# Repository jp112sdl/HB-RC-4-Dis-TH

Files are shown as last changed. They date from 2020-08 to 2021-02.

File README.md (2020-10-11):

# HB-RC-4-Dis-TH
## 4fach Wandtaster mit Display und Temperatursensor

Als Vorlage/Idee diente das [AVM FRITZ!DECT 440](https://avm.de/produkte/fritzdect/fritzdect-440/).

### Aufbau:

An den 4 Ecken befinden sich Taster, um über 4 verschiedenen Tasterkanäle Geräte zu steuern.<br/>
Unten mittig ist der Mode-Taster:
- langes Drücken = Anlernen oder (ganz lange) RESET
- kurzes Drücken = Anzeige der Tasterbeschriftung

In Ruhe werden auf dem Display die Temperatur (und wahlweise Luftfeuchtigkeit) sowie der Batteriezustand angezeigt.
Wird der Mode-Taster kurz gedrückt, erscheint für die in den Geräteeinstellungen festgelegte "Display Timeout" Zeit die Taster-Beschriftung.

Als Beschriftung lassen sich
- eine Überschrift (optional)
- 1 bis 2 Zeilen Beschriftungstext

hinterlegen

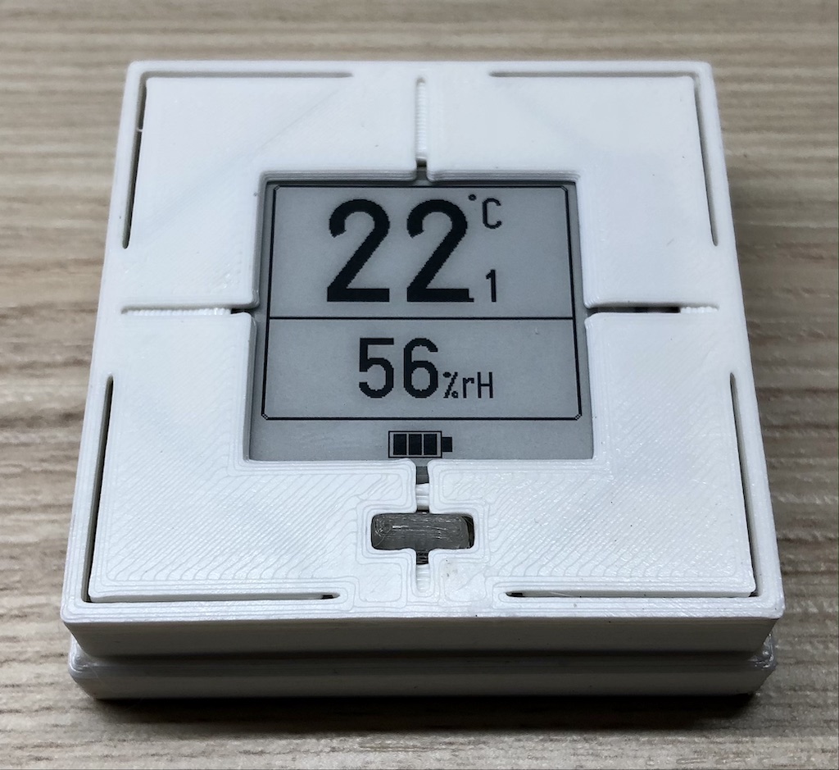
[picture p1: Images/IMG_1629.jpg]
device

<br><br>

### Prototyp

Nur Temperaturanzeige:<br>
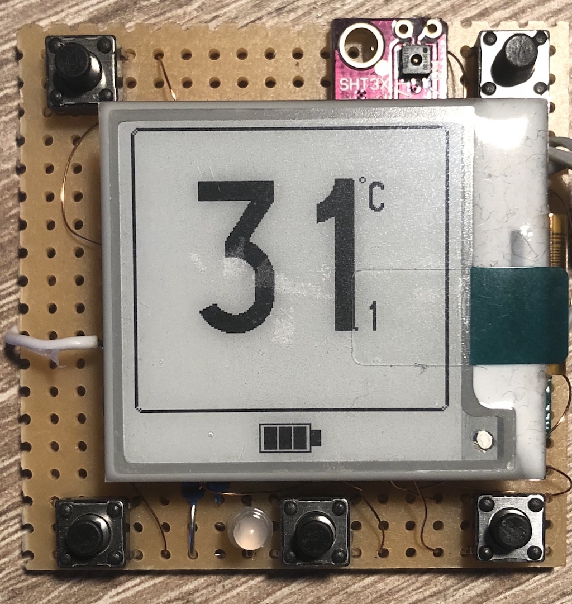
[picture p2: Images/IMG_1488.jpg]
<br><br>
Temperatur- und Luftfeuchtigkeit:<br>
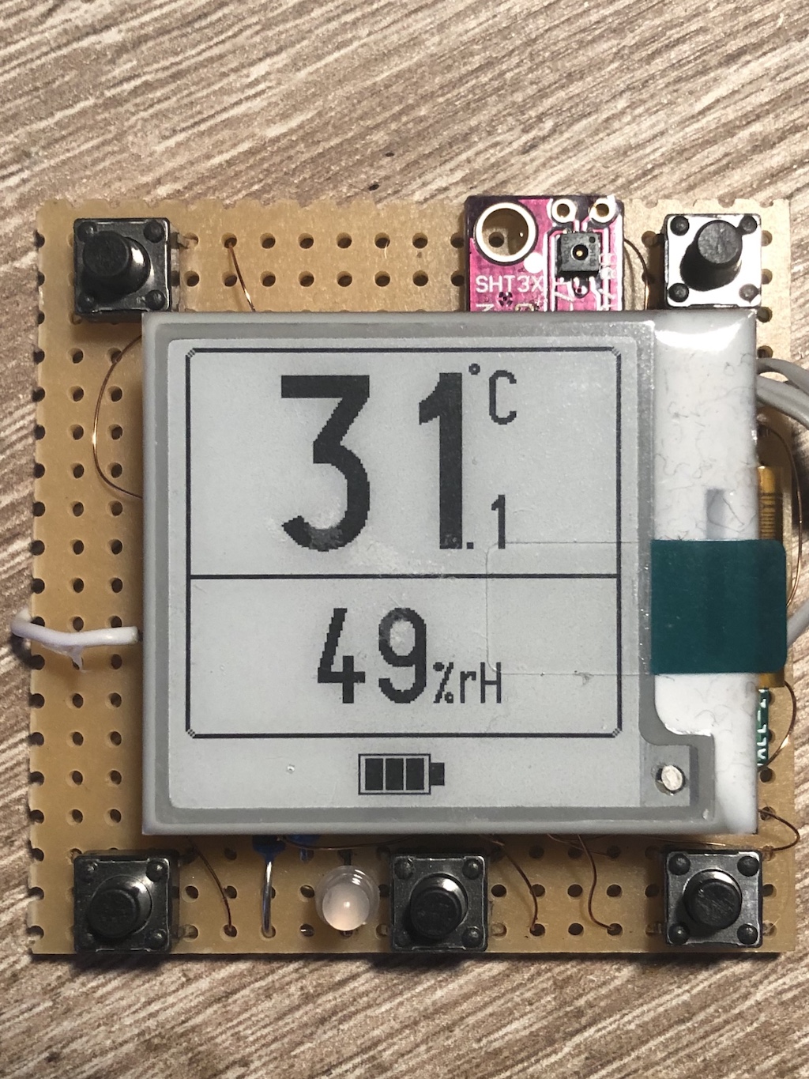
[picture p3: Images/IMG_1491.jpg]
<br><br>
Tasterbeschriftungen:<br>
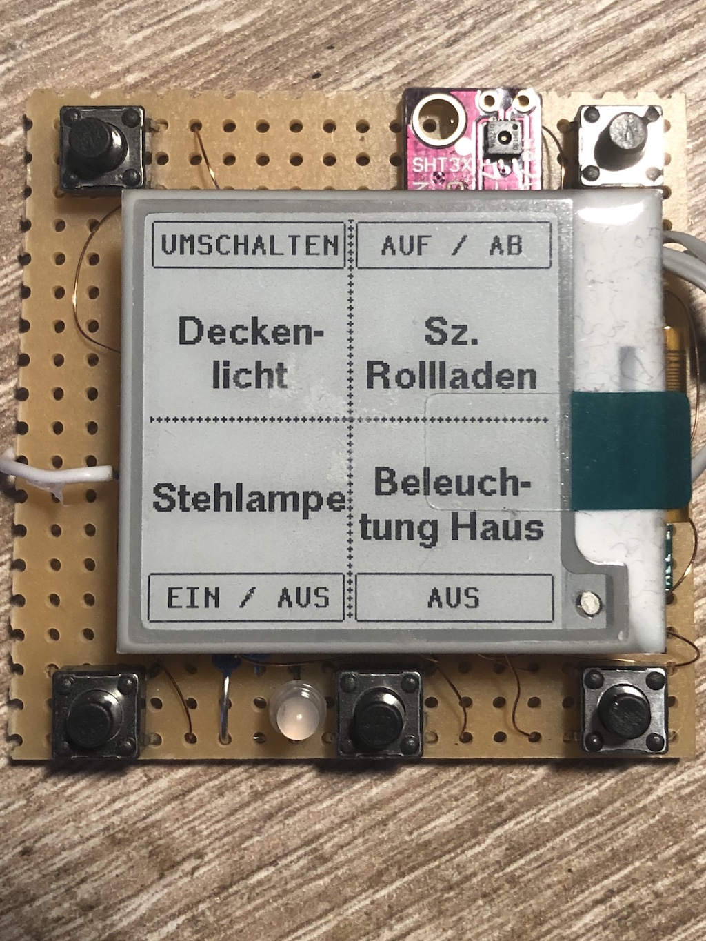
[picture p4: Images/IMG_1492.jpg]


### PCB Version 2.1

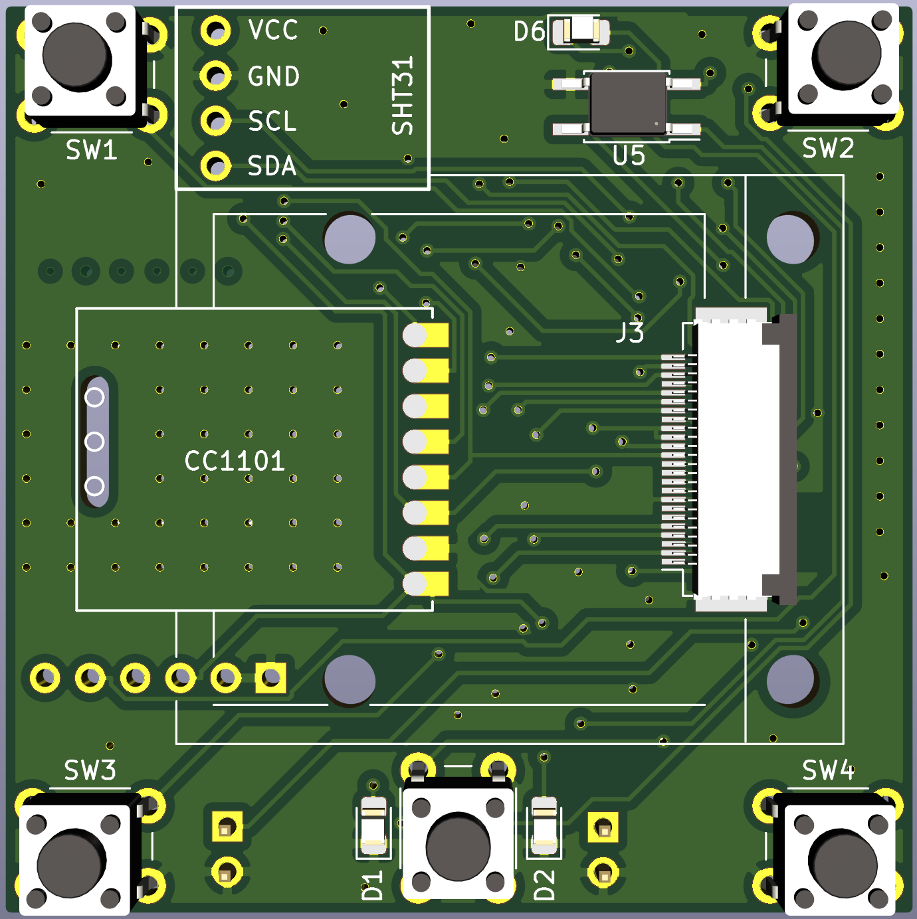
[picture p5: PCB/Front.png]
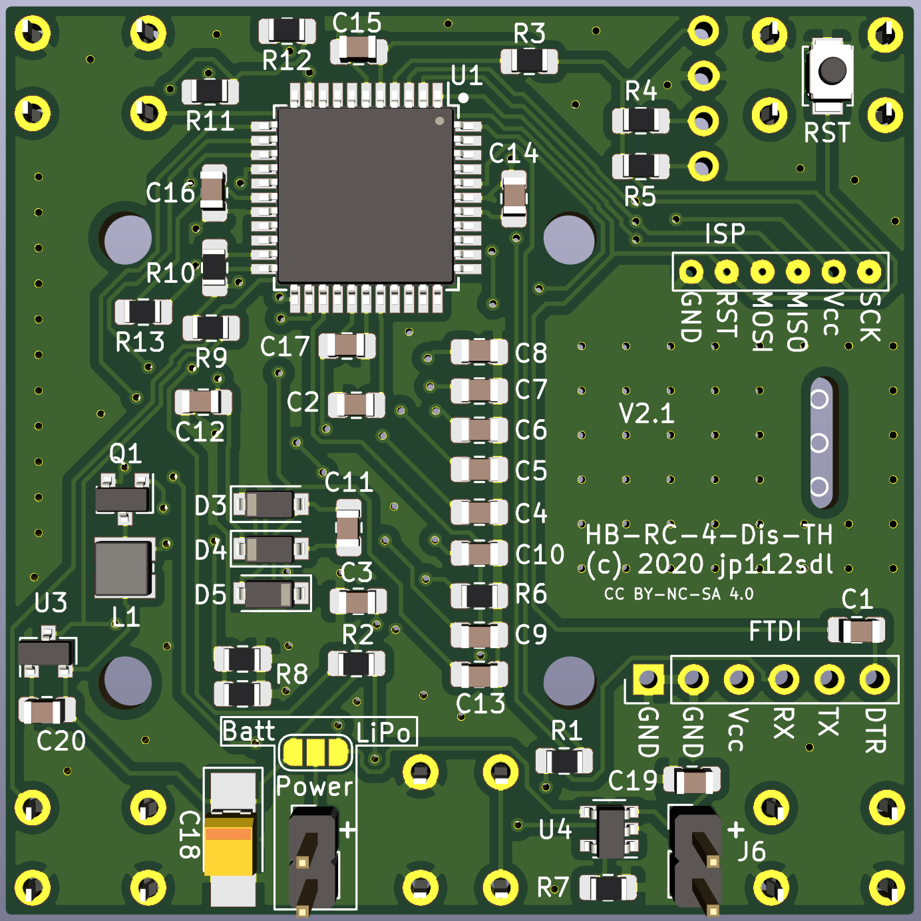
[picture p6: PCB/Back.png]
<br>
**[Abstandhalter](https://github.com/jp112sdl/HB-RC-4-Dis-TH/blob/master/PCB/HB-RC-4-Dis-TH%20ePaper%20Spacer.stl) zwischen Platine und ePaper:**<br/>
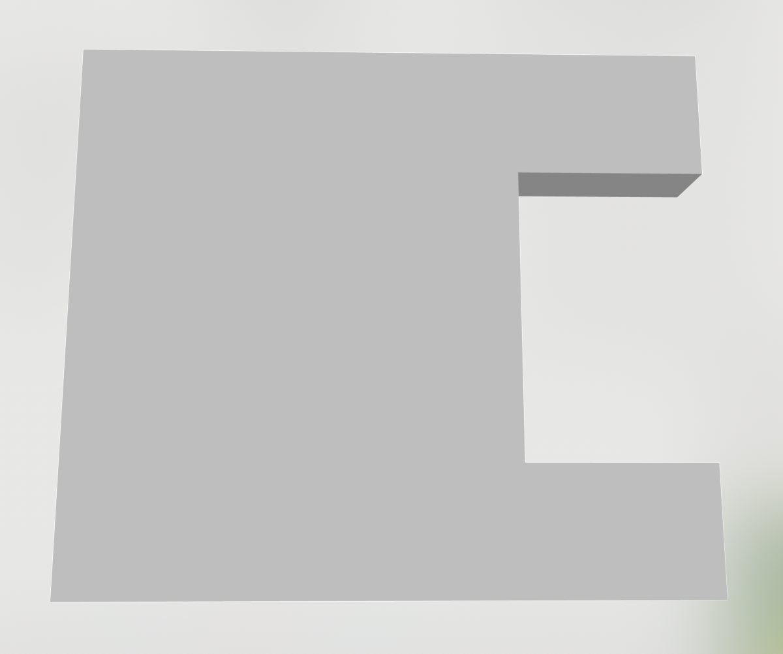
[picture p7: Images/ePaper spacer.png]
<br/>

**erste Version von JLCPCB**

<br/>
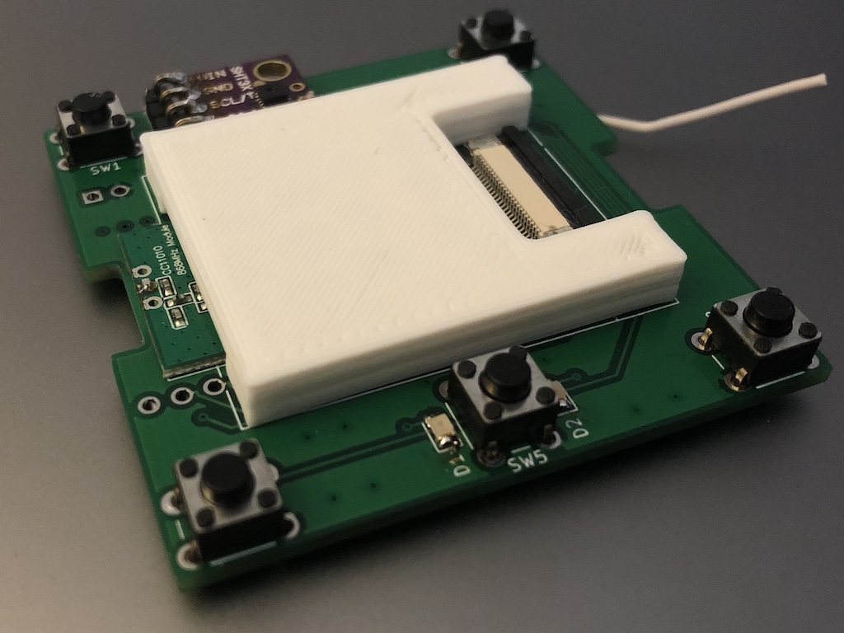
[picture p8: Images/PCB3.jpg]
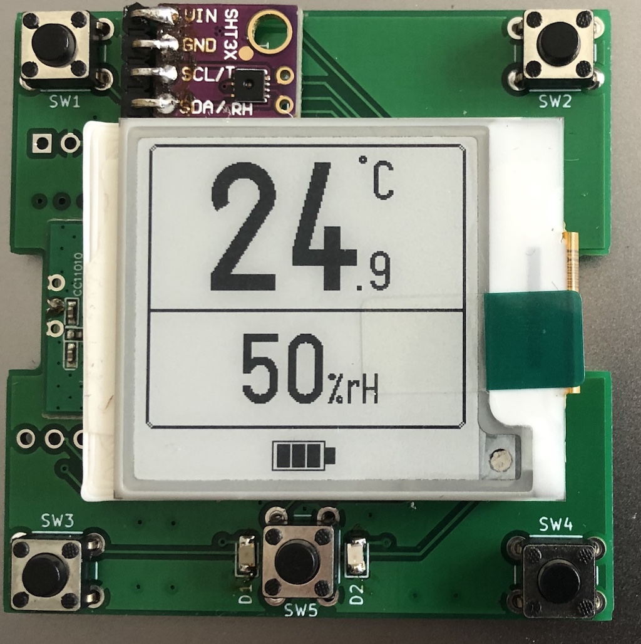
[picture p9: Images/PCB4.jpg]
<br/>

### CCU:

**Status und Bedienung -> Geräte**<br/>
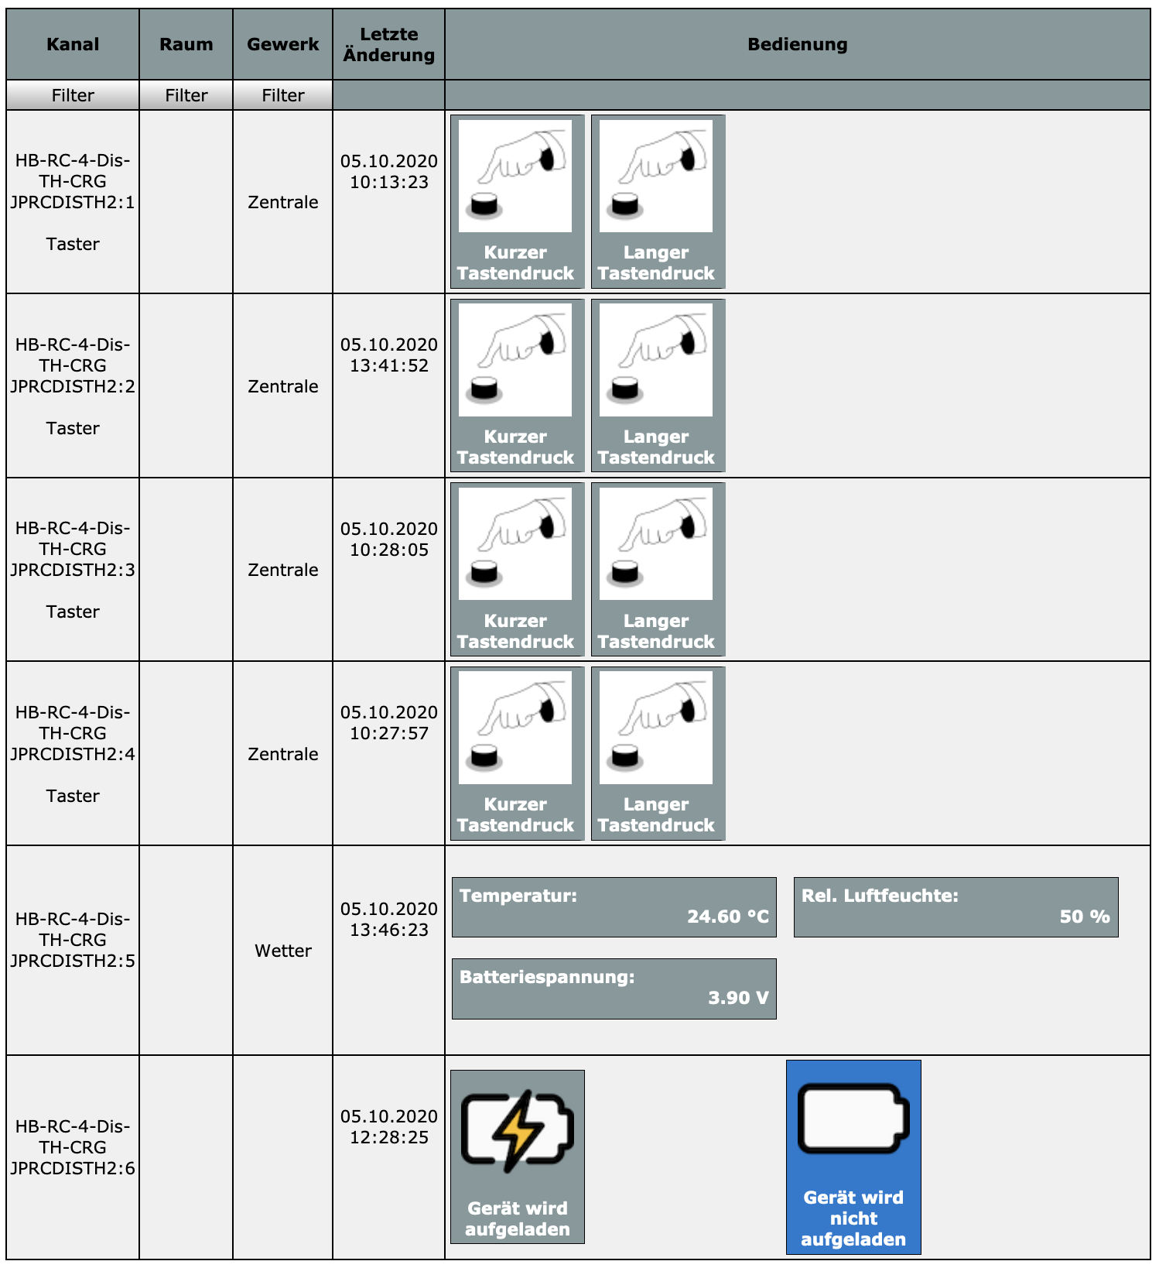
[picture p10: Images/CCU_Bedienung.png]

<br/>
**Einstellungen -> Geräte**<br/>
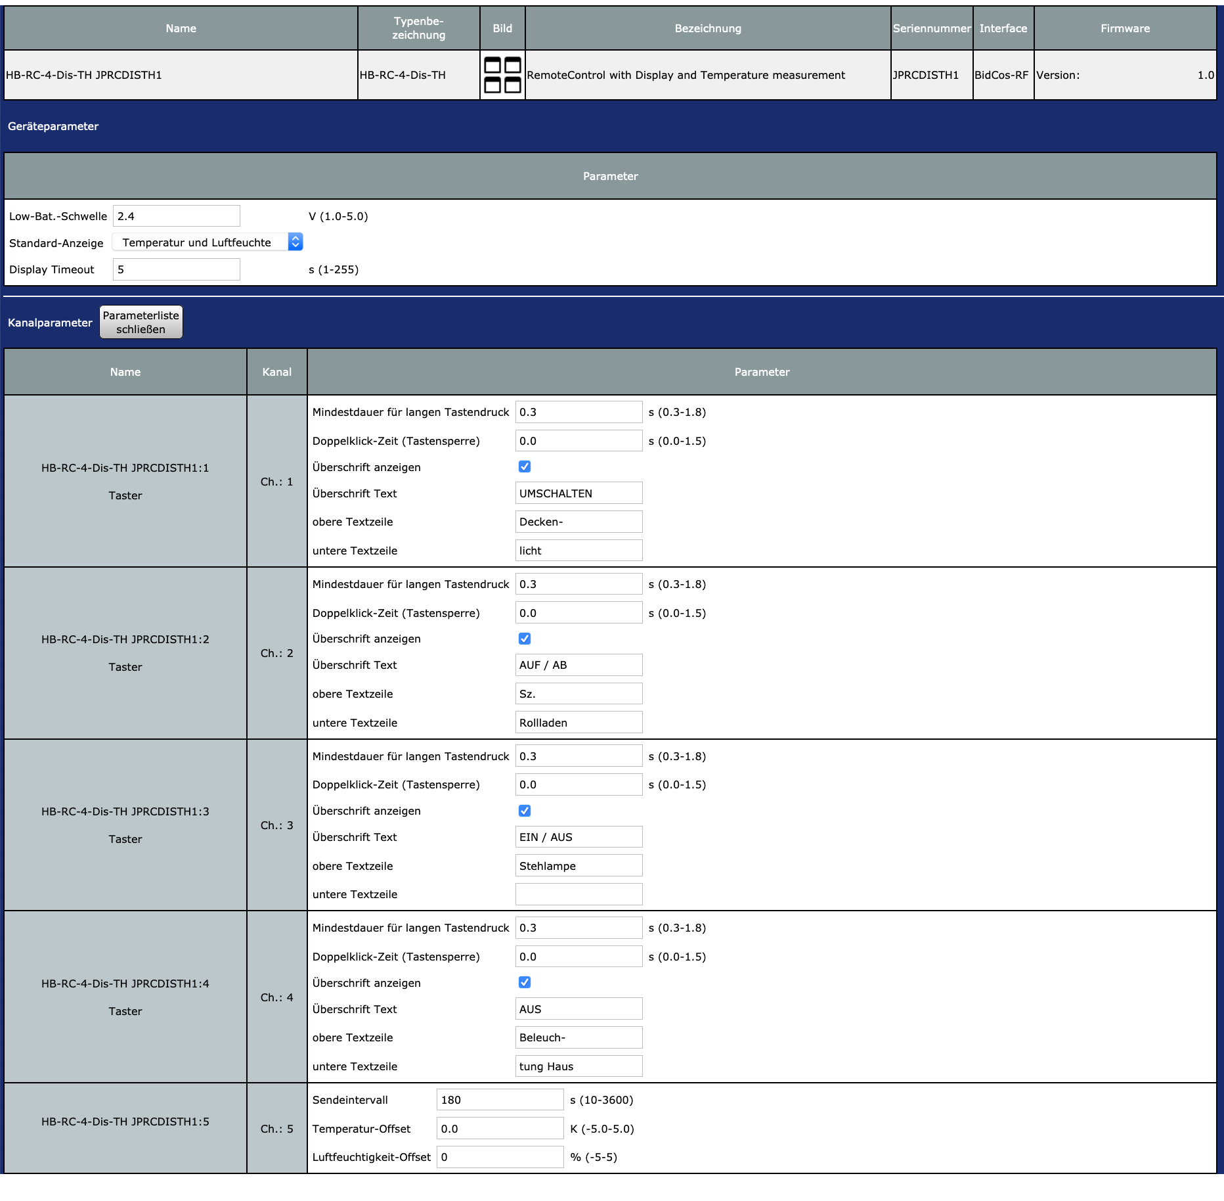
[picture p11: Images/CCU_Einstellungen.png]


### Zutaten
| Anzahl LiPo | Anzahl Batt | Bezeichnung | Bauform | Artikelnummer (Reichelt)|
|---|---|---|---|---|
|6  |6  | 100nF	| 0805	| X7R-G0805 100N
|11	|11	| 1µF/25V	| 0805	| KEM X5R0805 1,0U
|1	|1	| 100µ/10V	| 3528	| TAJ 3528 100/10
|2	|0	| 10µ/10V	| 0805	|KEM X5R0805 10U
|1	|1 | LED rot	| 0805	| OSO LHR974
|1	|1	| LED grün	| 0805	| OSO LGR971
|1	|0	| LED weiß	| 0805	| SLO SMD-W0805-0
|3	|3	| MBR0530	| SOD-123	| MBR0530T1G ONS 
|1	|1	| 68µH	| 3012	| L-1616FPS 68µ
|1	|1	| IRLML 6346 | SOT-23	| IRLML 6346
|1	|1	| ATMEGA 1284P-AU	| TQFP-44	| ATMEGA 1284P-AU
|1  |0  | MCP 1700T-3002E | SOT-23 | MCP 1700T-3002E
|1  |0  | MCP 73831T-2ACI | SOT-23-5 | MCP 73831T-2ACI
|1  |0	| PC357 | SO-4 | PC 357NJ0000F |
|2	|2	| 240	| 0805	| RND 0805 1 240
|1	|0	| 680	| 0805	| RND 0805 1 680
|1	|0	| 1k 	| 0805	| RND 0805 1 1,0K
|1	|0	| 2k2	| 0805	| RND 0805 1 2,2K
|1	|0	| 4k7	| 0805	| RND 0805 1 4,7k
|3	|3	| 10k	| 0805	| RND 0805 1 10K
|3	|1	| 100k	| 0805	| RND 0805 1 100K
|1	|0	| 470k	| 0805	| RND 0805 1 470K
|2	|2	| 1,0	| 0805	| SMD-0805 1,00
|5	|5	| Taster	| THT	| RND 210-00193
|1	|1	| Taster	| SMD	| https://de.aliexpress.com/item/1005001298009129.html
|1	|1	| ZIF-Sockel 24pol.	| ZIF SMD	| EA WF050-24S
|1 |1	| GoodDisplay ePaper 1,54" GDEW0154M09 ||https://de.aliexpress.com/item/4000993819257.html|
|1 |1 | SHT31 Sensor ||https://de.aliexpress.com/item/32850554676.html|
|1	|0	| 600mAh LiPo	| 	| https://www.ebay.de/itm/LiPo-Lithium-Polymer-3-7V-Akku-mit-BMS-PCB-Batterie-Handy-MP3-Tablet-Navi-LiIon/372814314688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 
|1	|0	| Induktionsladeempfänger	1x1,5cm | 	| https://de.aliexpress.com/item/4000086798457.html
|1	|0	| Induktionsladegerät	| 	| https://de.aliexpress.com/item/4000969719130.html

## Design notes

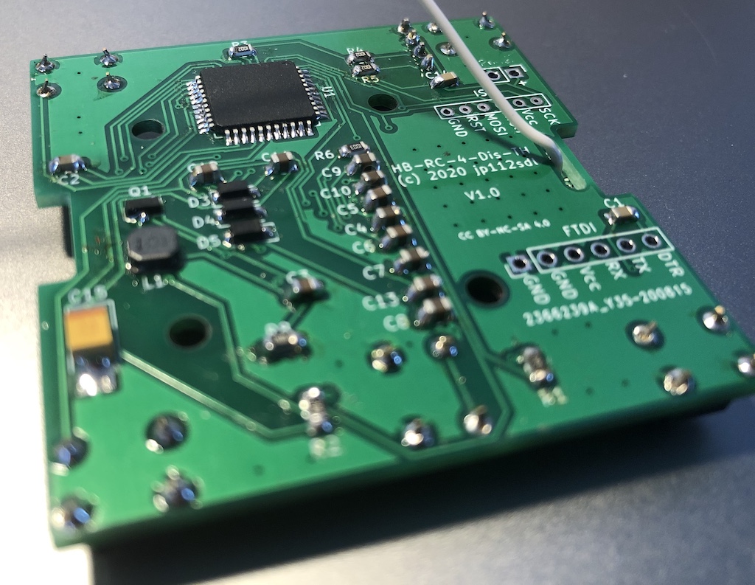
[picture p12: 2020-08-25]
Images/PCB2.jpg

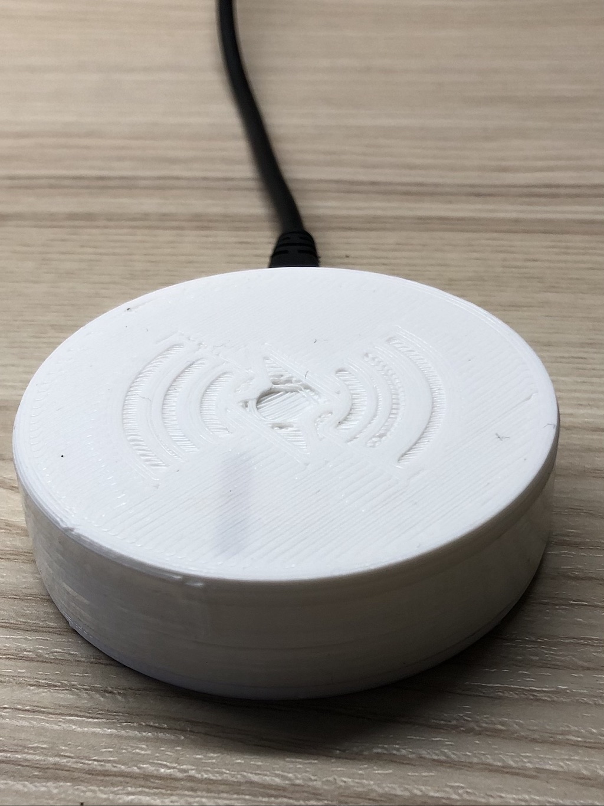
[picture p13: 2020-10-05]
Images/Charger.jpg

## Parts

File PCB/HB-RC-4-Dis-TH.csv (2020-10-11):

Reference | Value | Footprint | Datasheet
SW1 | T1 | Button_Switch_THT:SW_PUSH_6mm_H5mm | ~
SW2 | T2 | Button_Switch_THT:SW_PUSH_6mm_H5mm | ~
SW3 | T3 | Button_Switch_THT:SW_PUSH_6mm_H5mm | ~
SW4 | T4 | Button_Switch_THT:SW_PUSH_6mm_H5mm | ~
SW5 | Config | Button_Switch_THT:SW_PUSH_6mm_H5mm | ~
R1 | 240 | Resistor_SMD:R_0805_2012Metric_Pad1.15x1.40mm_HandSolder | ~
R2 | 240 | Resistor_SMD:R_0805_2012Metric_Pad1.15x1.40mm_HandSolder | ~
C2 | 100n | Capacitor_SMD:C_0805_2012Metric_Pad1.15x1.40mm_HandSolder | ~
R3 | 10k | Resistor_SMD:R_0805_2012Metric_Pad1.15x1.40mm_HandSolder | ~
C1 | 100n | Capacitor_SMD:C_0805_2012Metric_Pad1.15x1.40mm_HandSolder | ~
SHT31 | SHT31 | Connector_PinHeader_2.54mm:PinHeader_1x04_P2.54mm_Vertical | ~
R4 | 10k | Resistor_SMD:R_0805_2012Metric_Pad1.15x1.40mm_HandSolder | ~
R5 | 10k | Resistor_SMD:R_0805_2012Metric_Pad1.15x1.40mm_HandSolder | ~
FTDI1 | FTDI | Connector_PinHeader_2.54mm:PinHeader_1x06_P2.54mm_Vertical | ~
ISP1 | ISP | additional:PinPads_ISP | ~
D1 | LED rt | LED_SMD:LED_0805_2012Metric_Pad1.15x1.40mm_HandSolder | ~
D2 | gn | LED_SMD:LED_0805_2012Metric_Pad1.15x1.40mm_HandSolder | ~
C3 | 1µF/25V | Capacitor_SMD:C_0805_2012Metric_Pad1.15x1.40mm_HandSolder | ~
J3 | eInk | Connectors_Hirose:Hirose_FH12-24S-0.5SH_1x24_P0.5mm_Horizontal | ~
C8 | 1µF/25V | Capacitor_SMD:C_0805_2012Metric_Pad1.15x1.40mm_HandSolder | ~
C7 | 1µF/25V | Capacitor_SMD:C_0805_2012Metric_Pad1.15x1.40mm_HandSolder | ~
C6 | 1µF/25V | Capacitor_SMD:C_0805_2012Metric_Pad1.15x1.40mm_HandSolder | ~
C5 | 1µF/25V | Capacitor_SMD:C_0805_2012Metric_Pad1.15x1.40mm_HandSolder | ~
C4 | 1µF/25V | Capacitor_SMD:C_0805_2012Metric_Pad1.15x1.40mm_HandSolder | ~
C10 | 1µF/50V | Capacitor_SMD:C_0805_2012Metric_Pad1.15x1.40mm_HandSolder | ~
C9 | 1µF/50V | Capacitor_SMD:C_0805_2012Metric_Pad1.15x1.40mm_HandSolder | ~
Q1 | IRLML6346TRBPF | Package_TO_SOT_SMD:SOT-23 | https://www.infineon.com/dgdl/irlml2060pbf.pdf?fileId=5546d462533600a401535664b7fb25ee
L1 | 68µH | Inductor_SMD:L_Wuerth_MAPI-3012 | ~
R6 | 100k | Resistor_SMD:R_0805_2012Metric_Pad1.15x1.40mm_HandSolder | ~
R8-1 | 1 | Resistor_SMD:R_0805_2012Metric_Pad1.15x1.40mm_HandSolder | ~
D4 | MBR0530 | Diode_SMD:D_SOD-123 | ~
D5 | MBR0530 | Diode_SMD:D_SOD-123 | ~
D3 | MBR0530 | Diode_SMD:D_SOD-123 | ~
C12 | 1µF/50V | Capacitor_SMD:C_0805_2012Metric_Pad1.15x1.40mm_HandSolder | ~
C11 | 1µF/50V | Capacitor_SMD:C_0805_2012Metric_Pad1.15x1.40mm_HandSolder | ~
C13 | 1µF/50V | Capacitor_SMD:C_0805_2012Metric_Pad1.15x1.40mm_HandSolder | ~
U2 | CC1101 | additional:CC1101_Pads
C14 | 100n | Capacitor_SMD:C_0805_2012Metric_Pad1.15x1.40mm_HandSolder | ~
J5 | Power | Connector_PinHeader_2.54mm:PinHeader_1x02_P2.54mm_Vertical | ~
C18 | 100µ/10V | Capacitors_Tantalum_SMD:CP_Tantalum_Case-B_EIA-3528-21_Hand | ~
C15 | 100n | Capacitor_SMD:C_0805_2012Metric_Pad1.15x1.40mm_HandSolder | ~
C16 | 100n | Capacitor_SMD:C_0805_2012Metric_Pad1.15x1.40mm_HandSolder | ~
C17 | 100n | Capacitor_SMD:C_0805_2012Metric_Pad1.15x1.40mm_HandSolder | ~
U4 | MCP73831T-2ACI/OT | Package_TO_SOT_SMD:SOT-23-5 | http://ww1.microchip.com/downloads/en/DeviceDoc/20001984g.pdf
U3 | MCP1700T-3002E/CB | Package_TO_SOT_SMD:SOT-23
J6 | Batt | Connector_PinHeader_2.54mm:PinHeader_1x02_P2.54mm_Vertical | ~
C19 | 10/10 | Capacitor_SMD:C_0805_2012Metric_Pad1.15x1.40mm_HandSolder | ~
C20 | 10/10 | Capacitor_SMD:C_0805_2012Metric_Pad1.15x1.40mm_HandSolder | ~
R7 | 4k7 | Resistor_SMD:R_0805_2012Metric_Pad1.15x1.40mm_HandSolder | ~
R12 | 1k | Resistor_SMD:R_0805_2012Metric_Pad1.15x1.40mm_HandSolder | ~
D6 | LED wt | LED_SMD:LED_0805_2012Metric_Pad1.15x1.40mm_HandSolder | ~
U1 | ATmega1284P-AU | Package_QFP:TQFP-44_10x10mm_P0.8mm | http://ww1.microchip.com/downloads/en/DeviceDoc/Atmel-8272-8-bit-AVR-microcontroller-ATmega164A_PA-324A_PA-644A_PA-1284_P_datasheet.pdf
R9 | 470k | Resistor_SMD:R_0805_2012Metric_Pad1.15x1.40mm_HandSolder | ~
R10 | 100k | Resistor_SMD:R_0805_2012Metric_Pad1.15x1.40mm_HandSolder | ~
R11 | 680 | Resistor_SMD:R_0805_2012Metric_Pad1.15x1.40mm_HandSolder | ~
JP1 | SolderJumper_3_Open | Jumper:SolderJumper-3_P1.3mm_Open_RoundedPad1.0x1.5mm | ~
R13 | 100k | Resistor_SMD:R_0805_2012Metric_Pad1.15x1.40mm_HandSolder | ~
U5 | PC357 | Package_SO:SO-4_4.4x3.6mm_P2.54mm | https://global.sharp/products/device/lineup/data/pdf/datasheet/pc357n_e.pdf
R8-2 | 1 | Resistor_SMD:R_0805_2012Metric_Pad1.15x1.40mm_HandSolder | ~

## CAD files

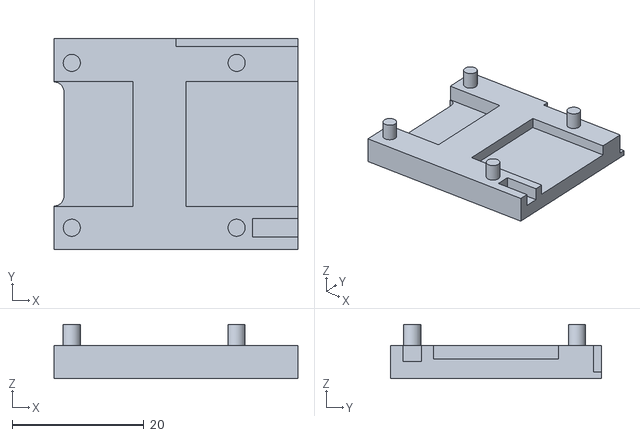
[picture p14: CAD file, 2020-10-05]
PCB/HB-RC-4-Dis-TH ePaper Spacer.stl
37.0 x 32.0 x 8.20

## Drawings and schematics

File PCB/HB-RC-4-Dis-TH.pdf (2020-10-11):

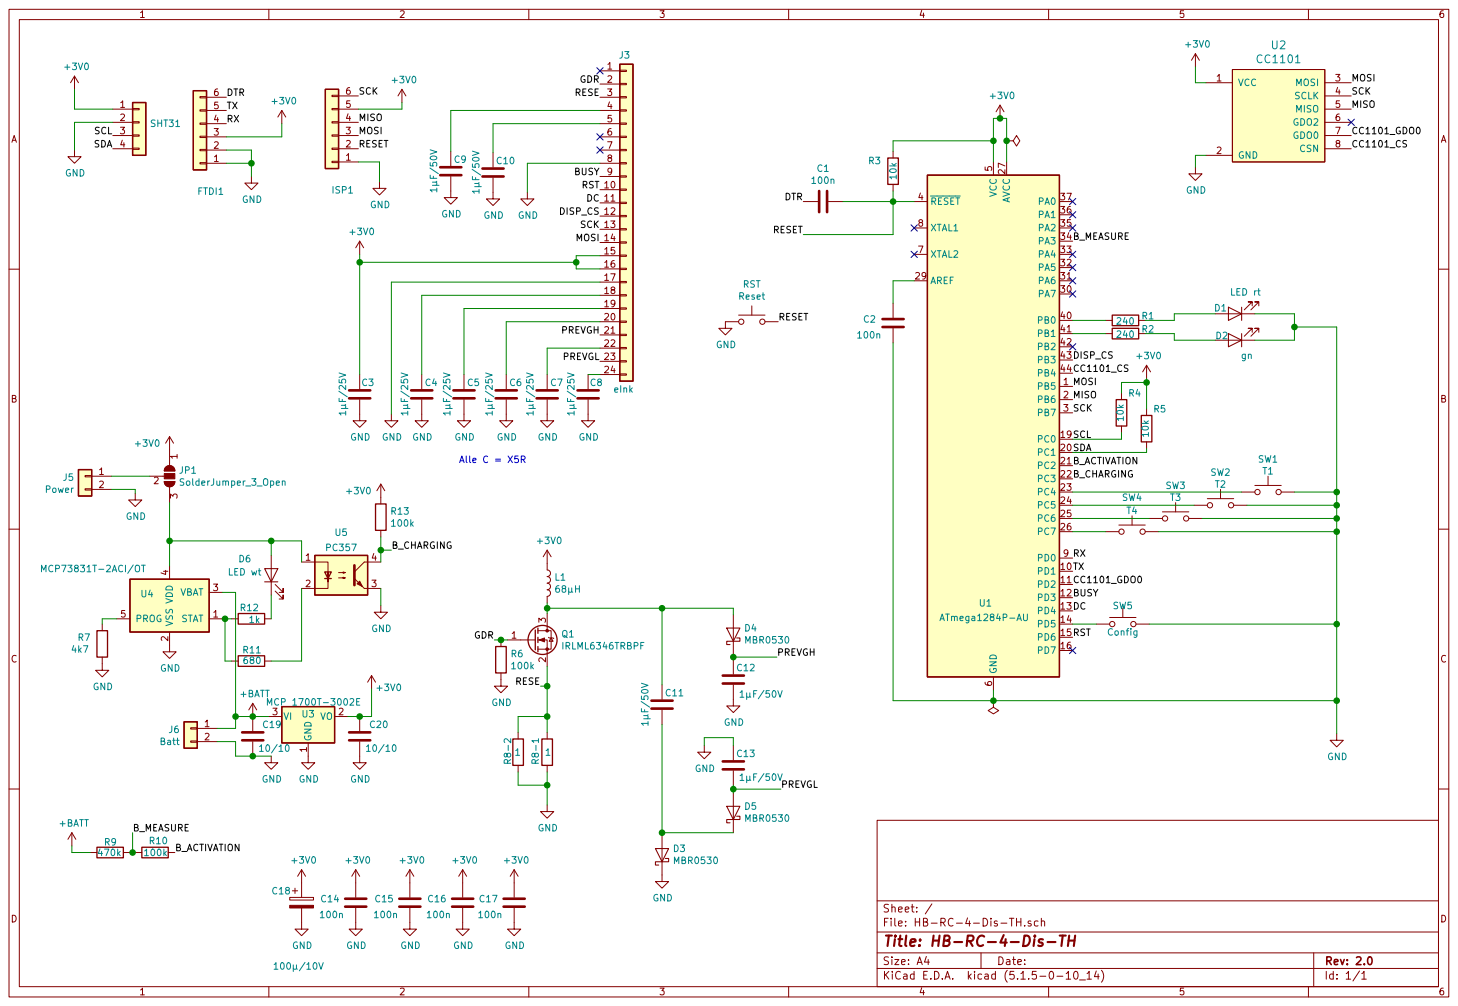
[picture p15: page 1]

LED rt +3V0 GND GND

File: HB-RC-4-Dis-TH.sch Sheet: /
Id: 1/1 Title: HB-RC-4-Dis-TH

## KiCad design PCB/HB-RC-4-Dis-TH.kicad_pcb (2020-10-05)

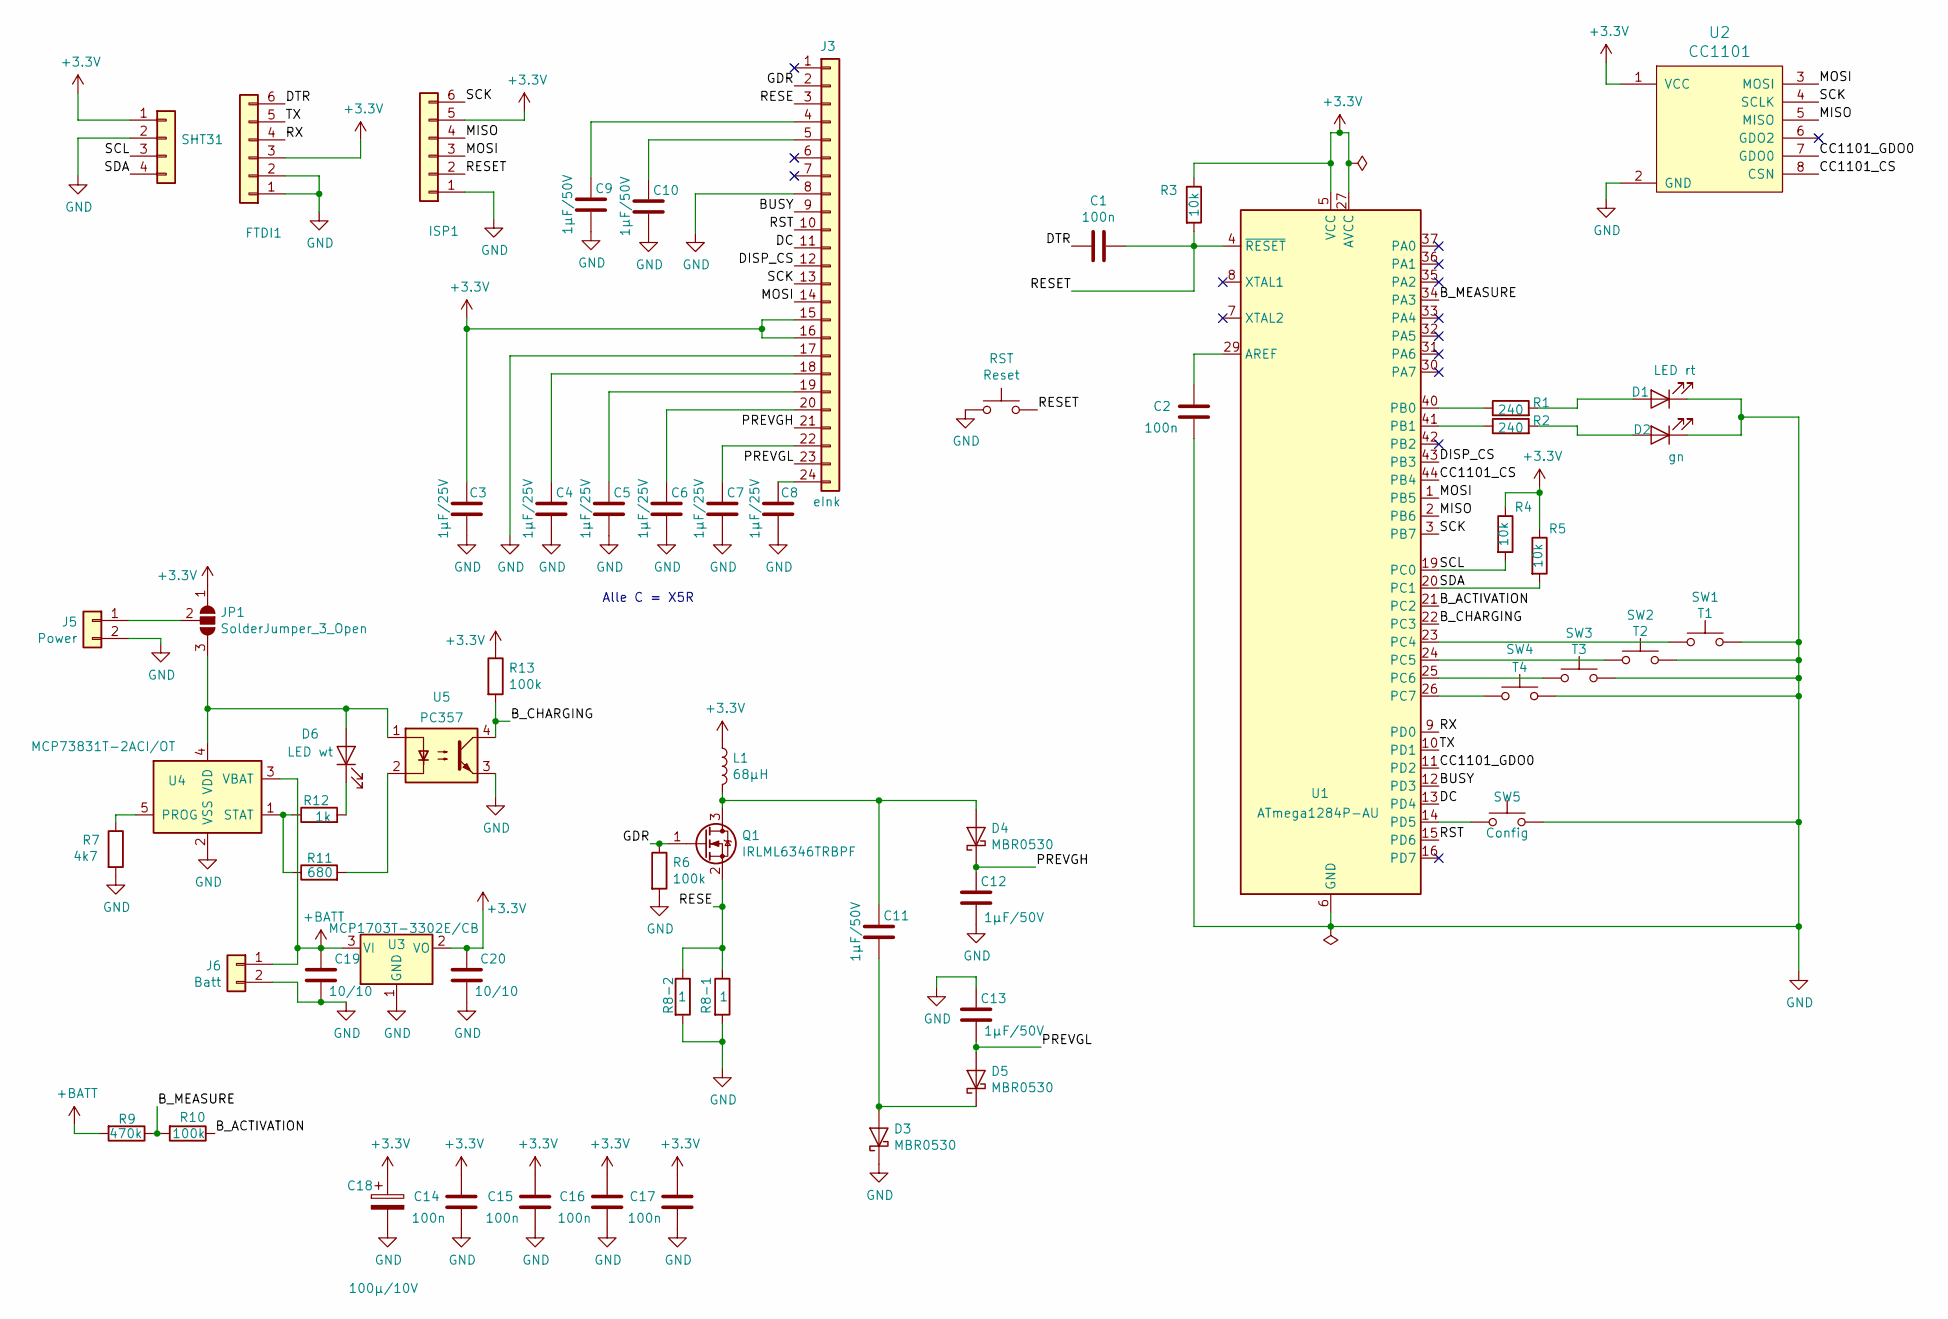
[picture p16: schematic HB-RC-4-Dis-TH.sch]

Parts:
C1, C2, C14, C15, C16, C17: 100n; C_0805_2012Metric_Pad1.15x1.40mm_HandSolder
C3, C4, C5, C6, C7, C8: 1µF/25V; C_0805_2012Metric_Pad1.15x1.40mm_HandSolder
C9, C10, C11, C12, C13: 1µF/50V; C_0805_2012Metric_Pad1.15x1.40mm_HandSolder
C18: 100µ/10V; CP_Tantalum_Case-B_EIA-3528-21_Hand
C19, C20: 10/10; C_0805_2012Metric_Pad1.15x1.40mm_HandSolder
D1: LED rt; LED_0805_2012Metric_Pad1.15x1.40mm_HandSolder
D2: gn; LED_0805_2012Metric_Pad1.15x1.40mm_HandSolder
D3, D4, D5: MBR0530; D_SOD-123
D6: LED wt; LED_0805_2012Metric_Pad1.15x1.40mm_HandSolder
FTDI1: FTDI; PinHeader_1x06_P2.54mm_Vertical
ISP1: ISP; PinPads_ISP
J3: eInk; Hirose_FH12-24S-0.5SH_1x24_P0.5mm_Horizontal
J5: Power; PinHeader_1x02_P2.54mm_Vertical
J6: Batt; PinHeader_1x02_P2.54mm_Vertical
JP1: SolderJumper_3_Open; SolderJumper-3_P1.3mm_Open_RoundedPad1.0x1.5mm
L1: 68µH; L_Wuerth_MAPI-3012
Q1: IRLML6346TRBPF; SOT-23
R1, R2: 240; R_0805_2012Metric_Pad1.15x1.40mm_HandSolder
R3, R4, R5: 10k; R_0805_2012Metric_Pad1.15x1.40mm_HandSolder
R6, R10, R13: 100k; R_0805_2012Metric_Pad1.15x1.40mm_HandSolder
R7: 4k7; R_0805_2012Metric_Pad1.15x1.40mm_HandSolder
R8-1, R8-2: 1; R_0805_2012Metric_Pad1.15x1.40mm_HandSolder
R9: 470k; R_0805_2012Metric_Pad1.15x1.40mm_HandSolder
R11: 680; R_0805_2012Metric_Pad1.15x1.40mm_HandSolder
R12: 1k; R_0805_2012Metric_Pad1.15x1.40mm_HandSolder
RST: Reset; SW_SPST_B3U-1000P
SHT31: SHT31; PinHeader_1x04_P2.54mm_Vertical
SW1: T1; SW_PUSH_6mm_H5mm
SW2: T2; SW_PUSH_6mm_H5mm
SW3: T3; SW_PUSH_6mm_H5mm
SW4: T4; SW_PUSH_6mm_H5mm
SW5: Config; SW_PUSH_6mm_H5mm
U1: ATmega1284P-AU; TQFP-44_10x10mm_P0.8mm
U2: CC1101; CC1101_Pads
U3: MCP1703T-3302E/CB; SOT-23
U4: MCP73831T-2ACI/OT; SOT-23-5
U5: PC357; SO-4_4.4x3.6mm_P2.54mm

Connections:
+3V3: C3.1, C14.1, C15.1, C16.1, C17.1, C18.1, C20.1, FTDI1.3, ISP1.5, J3.15, J3.16, JP1.1 (A), L1.1, R3.1, R4.1, R5.1, R13.1, SHT31.1, U1.5 (VCC), U1.17 (VCC), U1.27 (AVCC), U1.38 (VCC), U2.1 (VCC), U3.2 (VO)
+BATT: C19.1, J6.1, R9.2, U3.3 (VI), U4.3 (VBAT)
/BUSY: J3.9, U1.12 (PD3)
/B_ACTIVATION: R10.1, U1.21 (PC2)
/B_CHARGING: R13.2, U1.22 (PC3), U5.4
/B_MEASURE: R9.1, R10.2, U1.34 (PA3)
/CC1101_CS: U1.44 (PB4), U2.8 (CSN)
/CC1101_GDO0: U1.11 (PD2), U2.7 (GDO0)
/DC: J3.11, U1.13 (PD4)
/DISP_CS: J3.12, U1.43 (PB3)
/DTR: C1.2, FTDI1.6
/GDR: J3.2, Q1.1 (G), R6.1
/MISO: ISP1.4, U1.2 (PB6), U2.5 (MISO)
/MOSI: ISP1.3, J3.14, U1.1 (PB5), U2.3 (MOSI)
/PREVGH: C12.1, D4.1 (K), J3.21
/PREVGL: C13.2, D5.2 (A), J3.23
/RESE: J3.3, Q1.2 (S), R8-1.1, R8-2.1; also elsewhere on the board
/RESET: C1.1, ISP1.2, R3.2, RST.2, U1.4 (~RESET)
/RST: J3.10, U1.15 (PD6)
/RX: FTDI1.4, U1.9 (PD0)
/SCK: ISP1.6, J3.13, U1.3 (PB7), U2.4 (SCLK)
/SCL: R4.2, SHT31.3, U1.19 (PC0)
/SDA: R5.2, SHT31.4, U1.20 (PC1)
/TX: FTDI1.5, U1.10 (PD1)
GND: C2.2, C3.2, C4.2, C5.2, C6.2, C7.2, C8.2, C9.2, C10.2, C12.2, C13.1, C14.2, C15.2, C16.2, C17.2, C18.2, C19.2, C20.2, D1.1 (K), D2.1 (K), D3.1 (K), FTDI1.1, FTDI1.2, ISP1.1, J3.8, J3.17, J5.2, J6.2, R6.2, R7.2, R8-1.2, R8-2.2, RST.1, SHT31.2, SW1.2, SW2.2, SW3.2, SW4.2, SW5.2, U1.6 (GND), U1.18 (GND), U1.28 (GND), U1.39 (GND), U2.2 (GND), U3.1 (GND), U4.2 (VSS), U5.3; also elsewhere on the board
unnamed: C2.1, U1.29 (AREF)
unnamed: C4.1, J3.18
unnamed: C5.1, J3.19
unnamed: C6.1, J3.20
unnamed: C7.1, J3.22
unnamed: C8.1, J3.24
unnamed: C9.1, J3.4
unnamed: C10.1, J3.5
unnamed: C11.1, D4.2 (A), L1.2, Q1.3 (D)
unnamed: C11.2, D3.2 (A), D5.1 (K)
unnamed: D1.2 (A), R1.2
unnamed: D2.2 (A), R2.2
unnamed: D6.1 (K), R12.2
unnamed: D6.2 (A), JP1.3 (B), U4.4 (VDD), U5.1
unnamed: J5.1, JP1.2 (C)
unnamed: R1.1, U1.40 (PB0)
unnamed: R2.1, U1.41 (PB1)
unnamed: R7.1, U4.5 (PROG)
unnamed: R11.1, R12.1, U4.1 (STAT)
unnamed: R11.2, U5.2
unnamed: SW1.1, U1.23 (PC4)
unnamed: SW2.1, U1.24 (PC5)
unnamed: SW3.1, U1.25 (PC6)
unnamed: SW4.1, U1.26 (PC7)
unnamed: SW5.1, U1.14 (PD5)

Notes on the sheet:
Alle C = X5R

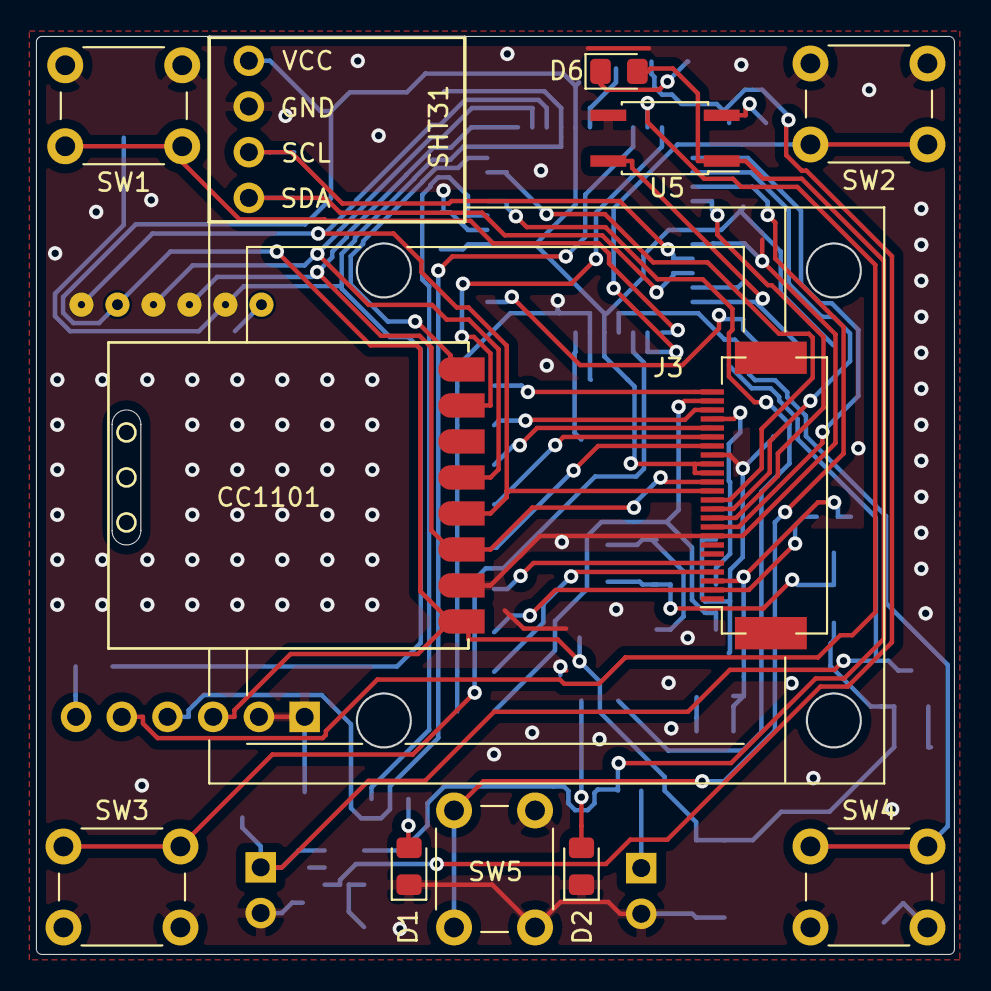
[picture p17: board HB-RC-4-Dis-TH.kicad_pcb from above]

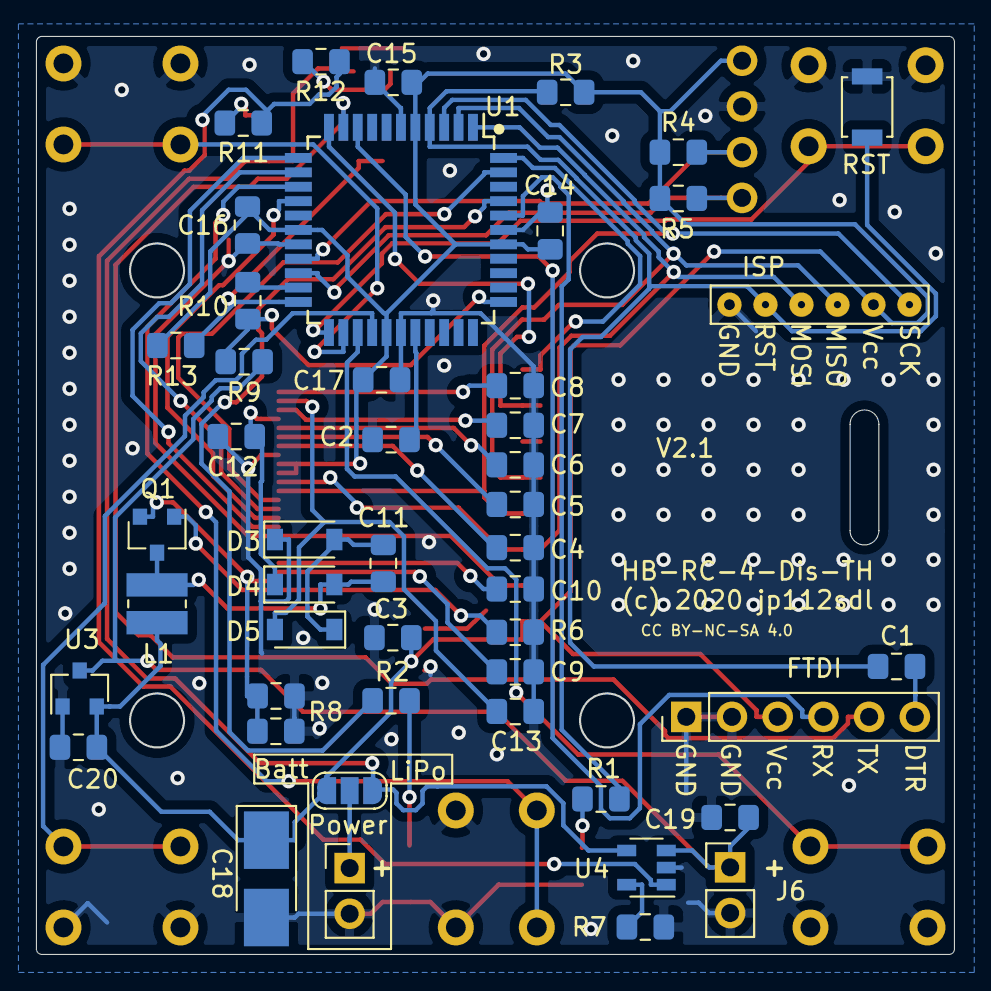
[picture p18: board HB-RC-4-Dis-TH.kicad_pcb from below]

Board: 2 copper layers, 51.0 x 51.0 mm, 60 parts (48 on the bottom side), 50 nets.

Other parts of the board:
R8: 1; R_0805_2012Metric_Pad1.15x1.40mm_HandSolder

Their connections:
/RESE: R8.1; also elsewhere on the board
GND: R8.2; also elsewhere on the board

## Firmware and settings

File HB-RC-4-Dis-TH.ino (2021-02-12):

//- -----------------------------------------------------------------------------------------------------------------------
// AskSin++
// 2016-10-31 papa Creative Commons - http://creativecommons.org/licenses/by-nc-sa/3.0/de/
// 2020-08-01 jp112sdl Creative Commons - http://creativecommons.org/licenses/by-nc-sa/3.0/de/
//- -----------------------------------------------------------------------------------------------------------------------
// ci-test=yes board=1284pBOB aes=no

// use Arduino IDE Board Setting: BOBUINO Layout

#define SENSOR_ONLY

#define USE_LIPO

#ifdef USE_LIPO

#define ChargerISR(chan,pin) class __##pin##ISRHandler { \
  public: \
  static void isr () { chan.irq(); } \
     }; \
  chan.init(pin); \
  if( digitalPinToInterrupt(pin) == NOT_AN_INTERRUPT ) \
    enableInterrupt(pin,__##pin##ISRHandler::isr,CHANGE); \
  else \
    attachInterrupt(digitalPinToInterrupt(pin),__##pin##ISRHandler::isr,CHANGE);

#define V_BATT_MAX          40
#define B_CHARGING_PIN      25
#define BATTERY_MEASUREMENT IrqExternalBatt<A4, 24>
#define DEVICE_MODEL        {0xf3, 0x2e}
#define ADDITIONAL_CHANNELS 2
#else
#define V_BATT_MAX          30
#define BATTERY_MEASUREMENT IrqInternalBatt
#define DEVICE_MODEL        {0xf3, 0x2f}
#define ADDITIONAL_CHANNELS 1
#endif

#define DEVICE_CHANNEL_COUNT 4
#define BATTERY_CRITICAL    19 // initial value

#define EI_NOTEXTERNAL
#include <EnableInterrupt.h>

//#include "LcdDisplay.h"
#include "ePaperDisplay.h"

#include <SPI.h>
#include <AskSinPP.h>
#include <LowPower.h>
#include <Register.h>
#include <MultiChannelDevice.h>
#include <Remote.h>
#include <ContactState.h>
#include <sensors/Sht31.h>

// make compatible with v5.0.0
#ifndef ASKSIN_PLUS_PLUS_VERSION_STR
  #define ASKSIN_PLUS_PLUS_VERSION_STR ASKSIN_PLUS_PLUS_VERSION
#endif

#define CC1101_CS_PIN       10 // PB4
#define CC1101_GDO0_PIN      2 // PD2
#define BTN01_PIN           26 // PC4
#define BTN02_PIN           27 // PC5
#define BTN03_PIN           28 // PC6
#define BTN04_PIN           29 // PC7
#define CONFIG_BUTTON_PIN    8 // PD5
#define LED_PIN_1            5 // PB1
#define LED_PIN_2            4 // PB0

#define TEXT_LENGTH               10
#define PEERS_PER_CHANNEL          8

#define SENSOR       Sht31<>

const struct DeviceInfo PROGMEM devinfo = {
  {0xf3, 0x2f, 0x02},       // Device ID
  "JPRCDISTH2",             // Device Serial
  DEVICE_MODEL,             // Device Model
  0x10,                     // Firmware Version
  as::DeviceType::Remote,   // Device Type
  {0x00, 0x00}              // Info Bytes
};

typedef LibSPI<CC1101_CS_PIN> SPIType;
typedef Radio<SPIType, CC1101_GDO0_PIN> RadioType;
typedef DualStatusLed<LED_PIN_1, LED_PIN_2> LedType;
typedef AskSin<LedType, BATTERY_MEASUREMENT, RadioType> Hal;
Hal hal;

DisplayType Display;

#define DREG_DISPLAYMODE 0x03
DEFREGISTER(Reg0, MASTERID_REGS, DREG_LOWBATLIMIT, DREG_LEDMODE, DREG_BACKONTIME, DREG_DISPLAYMODE, DREG_TRANSMITTRYMAX)
class HBList0 : public RegList0<Reg0> {
  public:
    HBList0(uint16_t addr) : RegList0<Reg0>(addr) {}

    bool defaultDisplayMode (uint8_t value) const { return this->writeRegister(DREG_DISPLAYMODE,7,0,value); }
    uint8_t defaultDisplayMode () const { return this->readRegister(DREG_DISPLAYMODE,7,0,0); }

    bool displayHalfDegree (uint8_t value) const { return this->writeRegister(DREG_DISPLAYMODE,1,3,value); }
    bool displayHalfDegree () const { return this->readRegister(DREG_DISPLAYMODE,1,3,0); }

    void defaults () {
      clear();
#ifdef USE_LIPO
      lowBatLimit(31);
#else
      lowBatLimit(24);
#endif
      backOnTime(10);
      defaultDisplayMode(0);
      displayHalfDegree(false);
      ledMode(1);
      transmitDevTryMax(6);
    }
};

DEFREGISTER(RCEPReg1, CREG_LONGPRESSTIME, CREG_AES_ACTIVE, CREG_DOUBLEPRESSTIME,
    0x36, 0x37, 0x38, 0x39, 0x3a, 0x3b, 0x3c, 0x3d, 0x3e, 0x3f,
    0x46, 0x47, 0x48, 0x49, 0x4a, 0x4b, 0x4c, 0x4d, 0x4e, 0x4f,
    0x56, 0x57, 0x58, 0x59, 0x5a, 0x5b, 0x5c, 0x5d, 0x5e, 0x5f,
    0x90)
class RCEPList1 : public RegList1<RCEPReg1> {
  public:
    RCEPList1 (uint16_t addr) : RegList1<RCEPReg1>(addr) {}

    bool showHeader (uint8_t value) const { return this->writeRegister(0x90, 0x01, 0, value & 0xff); }
    bool showHeader () const { return this->readRegister(0x90, 0x01, 0, false); }

    bool headerText (uint8_t value[TEXT_LENGTH]) const { for (int i = 0; i < TEXT_LENGTH; i++) { this->writeRegister(0x36 + i, value[i] & 0xff); } return true; }
    String headerText () const { String a = ""; for (int i = 0; i < TEXT_LENGTH; i++) { byte b = this->readRegister(0x36 + i, 0x20); if (b == 0x00) b = 0x20; a += char(b); } return a; }

    bool mainText1 (uint8_t value[TEXT_LENGTH]) const { for (int i = 0; i < TEXT_LENGTH; i++) { this->writeRegister(0x46 + i, value[i] & 0xff); } return true; }
    String mainText1 () const { String a = ""; for (int i = 0; i < TEXT_LENGTH; i++) { byte b = this->readRegister(0x46 + i, 0x20); if (b == 0x00) b = 0x20; a += char(b); } return a; }

    bool mainText2 (uint8_t value[TEXT_LENGTH]) const { for (int i = 0; i < TEXT_LENGTH; i++) { this->writeRegister(0x56 + i, value[i] & 0xff); } return true; }
    String mainText2 () const { String a = ""; for (int i = 0; i < TEXT_LENGTH; i++) { byte b = this->readRegister(0x56 + i, 0x20); if (b == 0x00) b = 0x20; a += char(b); } return a; }

    void defaults () {
      clear();
      //aesActive(false);
      uint8_t initValues[TEXT_LENGTH];
      memset(initValues, 0x00, TEXT_LENGTH);
      headerText(initValues);
      mainText1(initValues);
      mainText2(initValues);
    }
};

DEFREGISTER(THReg1, 0x01, 0x02, 0x20, 0x21)
class THList1 : public RegList1<THReg1> {
  public:
    THList1 (uint16_t addr) : RegList1<THReg1>(addr) {}

    bool sendIntervall (uint16_t value) const { return this->writeRegister(0x20, (value >> 8) & 0xff) && this->writeRegister(0x21, value & 0xff); }
    uint16_t sendIntervall () const { return (this->readRegister(0x20, 0) << 8) + this->readRegister(0x21, 0); }

    bool TemperatureOffsetIndex (uint8_t value) const { return this->writeRegister(0x01, (value) & 0xff); }
    uint8_t TemperatureOffsetIndex () const { return (int8_t)(this->readRegister(0x01, 0)); }

    bool HumidityOffsetIndex (uint8_t value) const { return this->writeRegister(0x02, (value) & 0xff); }
    uint8_t HumidityOffsetIndex () const { return (uint8_t)(this->readRegister(0x02, 0)); }

    void defaults () {
      clear();
      TemperatureOffsetIndex(7);
      HumidityOffsetIndex(5);
      sendIntervall(180);
    }
};

#ifdef USE_LIPO
DEFREGISTER(Reg1, CREG_AES_ACTIVE, CREG_MSGFORPOS, CREG_EVENTDELAYTIME, CREG_LEDONTIME)
class CRGSCList1 : public RegList1<Reg1> {
  public:
    CRGSCList1 (uint16_t addr) : RegList1<Reg1>(addr) {}
    void defaults () {
      clear();
      msgForPosA(1);
      msgForPosB(2);
      aesActive(false);
      eventDelaytime(0);
      ledOntime(100);
    }
};

class CRGPosition : public virtual Sensor {
public:
  enum State { NoPos=0, PosA, PosB, PosC };
protected:
  uint8_t  _position;
public:
  CRGPosition () : _position(NoPos) {}
  uint8_t position () { return _position; }
  uint8_t remap (uint8_t state) { return state; }
  uint32_t interval () { return seconds2ticks(5); }
};

class MyOnePinPosition : public CRGPosition {
private:
  uint8_t sens;
  bool _isCharging;
public:
  MyOnePinPosition () : sens(0), _isCharging(false) { _present = true; }

  void init (uint8_t pin) {
    sens=pin;
  }

  void measure (__attribute__((unused)) bool async=false) {
    _isCharging = ( AskSinBase::readPin(sens) == 0);
    static bool lastState=false;
    _position = ( _isCharging == true ) ? State::PosB : State::PosA;
    if (_isCharging != lastState) {
      if (_isCharging) {
        Display.showBatterySymbol(DisplayType::BS_CHARGING);
      } else {
        Display.setNextScreen(SCREEN_TEMPERATURE, true);
        hal.battery.resetCurrent();
      }
      lastState = _isCharging;
    }
  }

  bool isCharging() {
    return _isCharging;
  }
};

class CRGSCChannel : public StateGenericChannel<MyOnePinPosition,Hal,HBList0,CRGSCList1,DefList4,PEERS_PER_CHANNEL> {
public:
  typedef StateGenericChannel<MyOnePinPosition,Hal,HBList0,CRGSCList1,DefList4,PEERS_PER_CHANNEL> BaseChannel;
  CRGSCChannel () : BaseChannel() {};
  ~CRGSCChannel () {}

  void init (uint8_t pin) {
    BaseChannel::init();
    BaseChannel::possens.init(pin);
  }

  bool isCharging() {
    return possens.isCharging();
  }
};
#endif


class ConfigChannel : public RemoteChannel<Hal,PEERS_PER_CHANNEL,HBList0, RCEPList1>  {
public:
  ConfigChannel () : RemoteChannel()  {}
    virtual ~ConfigChannel () {}

    virtual void state(uint8_t s) {
      if (Display.currentScreen() == SCREEN_KEYLABELS) {
        Display.setNextScreen(SCREEN_KEYLABELS, false);
      }
      RemoteChannel::state(s);
    }

    void configChanged() {
      RemoteChannel::configChanged();

      uint8_t idx = number() -1;

      String ht = this->getList1().headerText();
      String mt1 = this->getList1().mainText1();
      String mt2 = this->getList1().mainText2();

      ht.trim();
      mt1.trim();
      mt2.trim();

      typedef struct rmap { char in; String out; } rmap_t;
      const rmap_t rplmap[] = { { '{', "ä" }, { '|', "ö" }, { '}', "ü" }, { '[', "Ä" }, { '#', "Ö" }, { '$', "Ü" }, { '~', "ß" }, { '\'', "=" } };
      for (uint8_t i = 0; i < 8; i++) {
         ht.replace(String(rplmap[i].in), rplmap[i].out);
         mt1.replace(String(rplmap[i].in), rplmap[i].out);
         mt2.replace(String(rplmap[i].in), rplmap[i].out);
      }

      DisplayFields[idx].showHeader = this->getList1().showHeader();
      DisplayFields[idx].HeaderText = ht;
      DisplayFields[idx].MainText1 = mt1;
      DisplayFields[idx].MainText2 = mt2;


      //DPRINT(F("RC (#"));DDEC(number());DPRINT(F(") showHeader : "));DDECLN(this->getList1().showHeader());
      //DPRINT(F("RC (#"));DDEC(number());DPRINT(F(") HeaderText : "));DPRINTLN(ht);
      //DPRINT(F("RC (#"));DDEC(number());DPRINT(F(") MainText1  : "));DPRINTLN(mt1);
      //DPRINT(F("RC (#"));DDEC(number());DPRINT(F(") MainText2  : "));DPRINTLN(mt2);
    }
};

class WeatherEventMsg : public Message {
  public:
    void init(uint8_t msgcnt, int16_t temp, uint8_t humidity, bool batlow, uint8_t bvolt) {
      uint8_t t1 = (temp >> 8) & 0x7f;
      uint8_t t2 = temp & 0xff;
      if ( batlow == true ) {
        t1 |= 0x80; // set bat low bit
      }
      Message::init(0xd, msgcnt, 0x70, BIDI | WKMEUP, t1, t2);
      pload[0] = humidity & 0xff;
      pload[1] = bvolt & 0xff;
    }
};

class WeatherChannel : public Channel<Hal, THList1, EmptyList, List4, PEERS_PER_CHANNEL, HBList0>, public Alarm {

    WeatherEventMsg msg;
    int16_t         temp;
    uint8_t         humidity;

    SENSOR          sensor;
    uint16_t        millis;

  public:
    WeatherChannel () : Channel(), Alarm(5), temp(0), humidity(0), millis(0) {}
    virtual ~WeatherChannel () {}


    // here we do the measurement
    void measure () {
      DPRINT("Measure...\n");
      sensor.measure();

      temp = sensor.temperature();
      humidity = sensor.humidity();

      temp += -35+5*this->getList1().TemperatureOffsetIndex();
      humidity += -5 + this->getList1().HumidityOffsetIndex();

      DPRINT(F("T/H = "));DDEC(temp);DPRINT(F("/"));DDECLN(humidity);
    }

    virtual void trigger (__attribute__ ((unused)) AlarmClock& clock) {

      // reactivate for next measure
      uint16_t updCycle = max(10,this->getList1().sendIntervall());
      tick = seconds2ticks(updCycle);
      clock.add(*this);

      DPRINT("Battery ext voltage: "); DDECLN(device().battery().voltageHighRes());
      measure();

      //send message
      msg.init(device().nextcount(), temp, humidity, device().battery().low(), device().battery().current());
      device().getList0().ledMode(false);
      device().broadcastEvent(msg);
      device().getList0().ledMode(true);

      //update display
      Display.setValues(temp, humidity, device().battery().current(), device().getList0().lowBatLimit());
      if (Display.currentScreen() == SCREEN_TEMPERATURE) Display.showTemp();
    }

    void setup(Device<Hal, HBList0>* dev, uint8_t number, uint16_t addr) {
      Channel::setup(dev, number, addr);
      sensor.init();
      sysclock.add(*this);
    }

    uint8_t status () const { return 0; }

    uint8_t flags () const { return 0; }

    virtual void configChanged () {
      DPRINT(F("WC (#"));DDEC(number());DPRINT(F(") TEMP OFFSET IDX : "));DDECLN(this->getList1().TemperatureOffsetIndex());
      DPRINT(F("WC (#"));DDEC(number());DPRINT(F(") HUMI OFFSET IDX : "));DDECLN(this->getList1().HumidityOffsetIndex());
      DPRINT(F("WC (#"));DDEC(number());DPRINT(F(") SEND INTERV     : "));DDECLN(this->getList1().sendIntervall());
    }
};

class MixDevice : public ChannelDevice<Hal, VirtBaseChannel<Hal, HBList0>, DEVICE_CHANNEL_COUNT+ADDITIONAL_CHANNELS, HBList0> {
  public:
#ifdef USE_LIPO
      VirtChannel<Hal, CRGSCChannel, HBList0> crgscChannel;
#endif
      VirtChannel<Hal, WeatherChannel, HBList0> weatherChannel;
      VirtChannel<Hal, ConfigChannel,  HBList0> remChannel[DEVICE_CHANNEL_COUNT];
  public:
    typedef ChannelDevice<Hal, VirtBaseChannel<Hal, HBList0>, DEVICE_CHANNEL_COUNT+ADDITIONAL_CHANNELS, HBList0> DeviceType;
    MixDevice (const DeviceInfo& info, uint16_t addr) : DeviceType(info, addr) {
      DeviceType::registerChannel(weatherChannel, 5);
#ifdef USE_LIPO
      DeviceType::registerChannel(crgscChannel, 6);
#endif
      for (uint8_t i = 0; i < DEVICE_CHANNEL_COUNT; ++i) DeviceType::registerChannel(remChannel[i], i + 1);
    }
    virtual ~MixDevice () {}

    ConfigChannel& btnChannel (uint8_t c) {
      return remChannel[c - 1];
    }

#ifdef USE_LIPO
    CRGSCChannel& crgChannel () {
      return crgscChannel;
    }
#endif

    virtual void configChanged () {
      uint8_t disptimeout = getList0().backOnTime();
      //DPRINT(F("List0 DISP TIMEOUT         : ")); DDECLN(this->getList0().backOnTime());
      Display.setScreenKeysTimeout(disptimeout);

      if (getList0().defaultDisplayMode() != Display.defaultDisplayMode()) {
        uint8_t ddm = getList0().defaultDisplayMode();
        DPRINT(F("List0 DEFAULT DISPLAYMODE  : ")); DDECLN(this->getList0().defaultDisplayMode());
        Display.defaultDisplayMode(ddm);
        if (Display.currentScreen() == SCREEN_TEMPERATURE) {
          Display.set(seconds2ticks(8), sysclock);
        }
      }

      Display.tempHalfDegree(getList0().displayHalfDegree());
      DPRINT(F("List0 SHOW TEMP HALFDEGREE : ")); DDECLN(getList0().displayHalfDegree());


      uint8_t lowbat = getList0().lowBatLimit();
      if( lowbat > 0 ) {
        battery().low(lowbat);
        battery().critical(lowbat - 1); // set critical bat value to "low bat" - 0.1V
      }
      DPRINT(F("List0 LOWBAT               : ")); DDECLN(this->getList0().lowBatLimit());
    }
};

MixDevice sdev(devinfo, 0x20);


class ConfBtn : public ConfigButton<MixDevice>  {
public:
  ConfBtn (MixDevice& i) : ConfigButton(i) {}
  virtual ~ConfBtn () {}

  virtual void state (uint8_t s) {
    uint8_t old = ButtonType::state();
    ButtonType::state(s);
    if( s == ButtonType::released ) {
#ifdef USE_LIPO
      if (sdev.crgChannel().isCharging() == false)
#endif
      if (Display.currentScreen() != Screen::SCREEN_KEYLABELS)
        Display.setNextScreen(Screen::SCREEN_KEYLABELS);
    }
    else if( s == ButtonType::longreleased ) {
      sdev.startPairing();
    }
    else if( s == ButtonType::longpressed ) {
      if( old == ButtonType::longpressed ) {
        sdev.reset(); // long pressed again - reset
      }
      else {
        sdev.led().set(LedStates::key_long);
      }
    }
  }
};

ConfBtn cfgBtn(sdev);
void setup() {
  DINIT(57600, ASKSIN_PLUS_PLUS_IDENTIFIER);

  Display.init();
  uint8_t serial[11];
  sdev.getDeviceSerial(serial);
  serial[10] = 0;
  Display.showInitScreen((char*)serial, sdev.getMasterID() > 0);

  sdev.init(hal);

  hal.battery.init(seconds2ticks(1),sysclock);
  hal.battery.critical(BATTERY_CRITICAL);

  remoteChannelISR(sdev.btnChannel(1), BTN01_PIN);
  remoteChannelISR(sdev.btnChannel(2), BTN02_PIN);
  remoteChannelISR(sdev.btnChannel(3), BTN03_PIN);
  remoteChannelISR(sdev.btnChannel(4), BTN04_PIN);
#ifdef USE_LIPO
  sdev.crgChannel().init(B_CHARGING_PIN);
  sdev.crgChannel().changed(true);
#endif

  buttonISR(cfgBtn, CONFIG_BUTTON_PIN);
  while (hal.battery.current() == 0);
  DPRINT("Battery voltage = ");DDECLN(hal.battery.voltageHighRes());
  sdev.initDone();
}

void loop() {
  bool worked = hal.runready();
  bool poll = sdev.pollRadio();
  if ( worked == false && poll == false ) {
    if (hal.battery.critical()) {
      Display.showBatterySymbol(DisplayType::BS_EMPTY);
#ifndef USE_LIPO
      hal.activity.sleepForever(hal);
#endif
    }
    hal.activity.savePower<Sleep<>>(hal);
  }
}

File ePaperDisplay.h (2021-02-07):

/*
 * ePaperDisplay.h
 *
 *  Created on: 9 Aug 2020
 *      Author: jp112sdl
 */

#ifndef EPAPERDISPLAY_H_
#define EPAPERDISPLAY_H_

#include <Adafruit_GFX.h>
#include <GxEPD2_BW.h>
#include "U8G2_FONTS_GFX.h"
#include <AskSinPP.h>
#include "ePaperIcons.h"

#define GxRST_PIN      9 // PC6
#define GxBUSY_PIN     3 // PC7
#define GxDC_PIN      30 // PC5
#define GxCS_PIN       7 // PB3

#define MAX_DISPLAY_BUFFER_SIZE 5000
#define MAX_HEIGHT(EPD) (EPD::HEIGHT <= MAX_DISPLAY_BUFFER_SIZE / (EPD::WIDTH / 8) ? EPD::HEIGHT : MAX_DISPLAY_BUFFER_SIZE / (EPD::WIDTH / 8))
GxEPD2_BW<GxEPD2_154_M09, MAX_HEIGHT(GxEPD2_154_M09)> display(GxEPD2_154_M09(/*CS=10*/ GxCS_PIN, /*DC=*/ GxDC_PIN, /*RST=*/ GxRST_PIN, /*BUSY=*/ GxBUSY_PIN)); // GDEW0154M09 200x200
U8G2_FONTS_GFX u8g2Fonts(display);
typedef enum screens { SCREEN_KEYLABELS, SCREEN_TEMPERATURE, SCREEN_EMPTYBATTERY, SCREEN_INIT } Screen;

#define BLACK       GxEPD_BLACK
#define WHITE       GxEPD_WHITE

#define FONT_KEYLABEL_TEXT        u8g2_font_helvB14_tf
#define FONT_HEIGHT_KEYLABEL_TEXT 18
#define FONT_KEYLABEL_HEADER      u8g2_font_9x18B_mf

#define FONT_TEMPERATURE          u8g2_font_logisoso78_tn
#define FONT_TEMPERATURE_UNIT     u8g2_font_logisoso24_tf
#define FONT_HUMIDITY             u8g2_font_logisoso42_tn
#define FONT_HUMIDITY_UNIT        u8g2_font_logisoso18_tr
#define FONT_TEMPERATURE_MAX      u8g2_font_logisoso92_tn
#define FONT_TEMPERATURE_MAX_UNIT u8g2_font_logisoso18_tf
#define FONT_INITSCREEN_BOLD      u8g2_font_helvB18_tr
#define FONT_INITSCREEN_REG       u8g2_font_helvR18_tr

using namespace as;

typedef struct {
  String HeaderText  = "";
  String MainText1   = "";
  String MainText2   = "";
  bool   showHeader  = true;
} DisplayRCConfig;
DisplayRCConfig DisplayFields[DEVICE_CHANNEL_COUNT];

class DisplayType : public Alarm {
  enum DefaultDisplayModes { DDM_TH = 0, DDM_T };
private:
  uint8_t screen;
  uint8_t current_screen;
  uint8_t timeout;
  int16_t temperature;
  uint8_t humidity;
  uint8_t defaultdisplaymode;
  bool displaymodehaschanged;
  uint16_t battery_current;
  uint16_t battery_low;
  bool   temphalfdegree;
private:
  uint16_t centerPosition(const char * text) { return centerPosition(display.width(), text); }
  uint16_t centerPosition(uint8_t width, const char * text) { return (width / 2) - (u8g2Fonts.getUTF8Width(text) / 2); }
public:
  DisplayType () :  Alarm(seconds2ticks(1)), screen(SCREEN_KEYLABELS), current_screen(SCREEN_INIT), timeout(10), temperature(0), humidity(0), defaultdisplaymode(DDM_TH), displaymodehaschanged(false), battery_current(0), battery_low(0), temphalfdegree(false) {}
  virtual ~DisplayType () {}

  void set (uint32_t t,AlarmClock& clock) {
    clock.cancel(*this);
    Alarm::set(t);
    clock.add(*this);
  }
  virtual void trigger (__attribute__((unused)) AlarmClock& clock) {
    switch (screen) {
    case SCREEN_KEYLABELS:
      showKeyLabels();
      set(seconds2ticks(timeout),sysclock);
      break;
    case Screen::SCREEN_TEMPERATURE:
      showTemp();
      break;
    }
  }
  void setNextScreen(Screen scr, bool immediate=false) {
    screen = scr;
    set(millis2ticks(immediate? 5 : timeout),sysclock);
  }

  void setScreenKeysTimeout(uint8_t t) {
    timeout = t;
  }

  void displayModeHasChanged(bool c) {
    displaymodehaschanged = c;
  }

  bool displayModeHasChanged() {
    return displaymodehaschanged;
  }

  void defaultDisplayMode(uint8_t m) {
    if (m != defaultdisplaymode) displayModeHasChanged(true);
    defaultdisplaymode = m;
  }

  uint8_t defaultDisplayMode() {
    return defaultdisplaymode;
  }

  void tempHalfDegree(bool b){
    temphalfdegree = b;
  }

  bool tempHalfDegree() {
    return temphalfdegree;
  }

  void setValues(int16_t t, uint8_t h, uint16_t b, uint16_t bl) {
    if (temphalfdegree == true) {
      temperature = t > 0 ? (t+2)/5*5 : (t-2)/5*5 ;
    } else {
      temperature = t;
    }
    humidity = h;
    battery_current = b;
    battery_low = bl;
  }

  uint8_t currentScreen() {
    return current_screen;
  }

  void showTemp() {
      const char * t_unit = "°C";
      const char * h_unit = "%rH";

      static int16_t last_temperature = 0;
      static uint8_t last_humidity = 0;
      static uint8_t last_battpct = 0;

      uint8_t range = V_BATT_MAX - battery_low;
      if (battery_current > V_BATT_MAX) battery_current = V_BATT_MAX;
      uint8_t diff = battery_low > battery_current ? 0 : battery_current - battery_low;
      uint8_t battpct = (100 * diff) / range;

      uint8_t updateMode = 0;  // 0 = no update, 1 = full update, 2 = partial update

      //draw main frame on first call
      if (current_screen != Screen::SCREEN_TEMPERATURE || displayModeHasChanged() == true) {
        display.fillScreen(GxEPD_WHITE);

        display.drawRoundRect(5, 2, display.width() - 10, display.height() - 30, 5, BLACK);
        display.drawRoundRect(4, 1, display.width() - 8, display.height() - 28, 5, BLACK);
        if (defaultdisplaymode == DDM_TH) {
          for (uint8_t i = 1; i < 3; i ++)
            //horizontal divider temp / humidity
            display.drawLine(6, (display.height() / 2) + i, display.width()-6, (display.height() / 2) + i, BLACK);
        }

        //battery icon
        display.drawRect(display.width()/2-20, display.height()-20, 32, 18, BLACK);
        display.fillRect(display.width()/2-20+32, display.height()-16, 6, 10, BLACK);
        updateMode = 1;
      }

      if (this->temperature != last_temperature || current_screen != Screen::SCREEN_TEMPERATURE || displayModeHasChanged() == true) {

        int8_t  t_int = this->temperature / 10;
        uint8_t t_dec = this->temperature % 10;

        if (defaultdisplaymode == DDM_TH) {
          display.fillRect(6,6,display.width()-12,(display.height() / 2) - 6, WHITE);

          u8g2Fonts.setFont(FONT_TEMPERATURE);
          uint8_t t_width = u8g2Fonts.getUTF8Width(String(t_int).c_str());
          u8g2Fonts.setFont(FONT_TEMPERATURE_UNIT);
          uint8_t t_unit_width = u8g2Fonts.getUTF8Width(String(t_unit).c_str());

          u8g2Fonts.setFont(FONT_TEMPERATURE);
          u8g2Fonts.setCursor((display.width() / 2) - ((t_unit_width + t_width) / 2) - 6, display.height() - 110);
          u8g2Fonts.print(t_int);

          u8g2Fonts.setFont(FONT_TEMPERATURE_UNIT);
          u8g2Fonts.setCursor((display.width() / 2) + ((t_width / 2) / 2) + 6, display.height() - 165);
          u8g2Fonts.print(t_unit);
          u8g2Fonts.setCursor((display.width() / 2) + ((t_width / 2) / 2) + 4, display.height() - 110);
          u8g2Fonts.print(".");
          u8g2Fonts.print(t_dec);
        } else {
          display.fillRect(6,6,display.width()-12,display.height() - 36, WHITE);

          u8g2Fonts.setFont(FONT_TEMPERATURE_MAX);
          uint8_t t_width = u8g2Fonts.getUTF8Width(String(t_int).c_str());
          u8g2Fonts.setFont(FONT_TEMPERATURE_MAX_UNIT);
          uint8_t t_unit_width = u8g2Fonts.getUTF8Width(String(t_unit).c_str());
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

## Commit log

2020-08-15 changed position of temperature value
2020-08-15 add PCB
    [HB-RC-4-Dis-TH-B_Cu.gbr, HB-RC-4-Dis-TH-B_Mask.gbr, HB-RC-4-Dis-TH-B_Paste.gbr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]
2020-08-15 update pcb
    [HB-RC-4-Dis-TH-B_Cu.gbr, HB-RC-4-Dis-TH-B_Mask.gbr, HB-RC-4-Dis-TH-B_Paste.gbr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]
2020-08-15 add epaper display spacer stl
    [HB-RC-4-Dis-TH ePaper Spacer.stl]
2020-08-15 add via
    [HB-RC-4-Dis-TH.kicad_pcb]
2020-08-16 update pcb v1.1 (added decoupling capacitors)
    [HB-RC-4-Dis-TH-B_Cu.gbr, HB-RC-4-Dis-TH-B_Mask.gbr, HB-RC-4-Dis-TH-B_Paste.gbr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]
2020-08-19 use multiple pin layouts
2020-08-25 modified pins for pcb
2020-08-25 changed resistor values
    [HB-RC-4-Dis-TH.sch]
2020-08-25 update spacer
    [HB-RC-4-Dis-TH ePaper Spacer.stl]
2020-08-26 shrink pcb to 51x51
    [HB-RC-4-Dis-TH.dsn, HB-RC-4-Dis-TH.kicad_pcb]
2020-09-01 update for pcb v1.2
    [HB-RC-4-Dis-TH ePaper Spacer.stl]
2020-09-01 change AVR to 1284P
    [HB-RC-4-Dis-TH.sch]
2020-09-06 add BOM
    [BOM.xlsx, HB-RC-4-Dis-TH.csv]
2020-09-06 add battery empty symbol and function to display temperature in .5 degree steps
2020-09-06 fix battery symbol
2020-09-27 update pcb V2.1
    [HB-RC-4-Dis-TH-B_Cu.gbr, HB-RC-4-Dis-TH-B_Mask.gbr, HB-RC-4-Dis-TH-B_Paste.gbr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]
2020-10-11 replaced 3.3V LDO with 3.0V
    [HB-RC-4-Dis-TH.sch]
2020-10-11 upbade bom
    [HB-RC-4-Dis-TH.csv]
2020-12-03 added temperature/humidity offset

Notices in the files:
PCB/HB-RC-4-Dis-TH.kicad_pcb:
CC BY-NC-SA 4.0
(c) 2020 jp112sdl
